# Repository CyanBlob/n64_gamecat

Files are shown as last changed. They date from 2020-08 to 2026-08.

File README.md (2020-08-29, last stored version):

# N64 GameCat

This is a free, open-source implementation of a Nintendo 64 cheating device, akin to the GameShark. It's currently based around the Kendryte K210 SoC (using the Sipeed MAiX BiT breakout), which I chose due to the high number of configurable IO (the N64 cartridge has 50 pins, though many of those aren't necessary for this project). I may eventually add support for ESP32 chips to the GameCat as well.

## Building
This is a PlatformIO project (https://platformio.org/), so building and uploading are relatively straightforward. Simply install PlatformIO (and make sure to add it to your $PATH), and then run `platformio run --target upload --target monitor` with the MAiX BiT plugged in. If it complains about `udev` rules, follow the link it provides.

## Circuits/schematics
I have some test PCBs on order (files are in the `/pcb` directory, made with KiCad EDA). Once I get the design for those finalized it should be as simple as ordering a PCB, soldering the MCU on, and soldering on a cartridge slot
#### Note:
When ordering a cartridge slot, it's important to get one with 2.5mm pin spacing. I've seen several only with 2.54mm spacing, which may not work on this PCB (or with the cartridges in general). I'm using this $2.50 version from AliExpress: https://www.aliexpress.com/item/33002915153.html?spm=a2g0s.9042311.0.0.1ec84c4dN5ezxJ

## FAQ
### Why do this?
I was bored, and that's literally the only reason. If you want to cheat at N64 games, you're likely much better off with an emulator.

### I looked at the PCB. Won't the cartridge end up being parallel with the console if I solder the cartridge slot on it?
Yes.
### Why?
I have no idea what I'm doing.

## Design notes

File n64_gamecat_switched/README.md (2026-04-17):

# N64 Gamecat (Switched)

An RP2350-based interposer that sits between an N64 cartridge and the console,
watches reads on the cart bus, and injects override values for chosen
addresses. Useful for cheats, patching protected boot words, or serving
synthetic data to the console.

This document covers the hardware topology, the N64 cartridge bus protocol as
it appears on the wire, and how the firmware's two PIO state machines plus the
C main loop cooperate to pull it off in real time.

---

## 1. Hardware topology

The board uses a bidirectional bus switch (CBT family) that can electrically
isolate the cartridge from the console's multiplexed address/data bus. The
`CART_EN` GPIO is wired directly to the CBT's active-low `/OE`, so
`CART_EN = 0` closes the switch (cart and console talk directly; the RP2350
just observes) and `CART_EN = 1` opens it (cart is cut off; the RP2350 drives
AD[15:0] for a single /READ pulse).

```
             console edge                              cartridge edge
                  │                                         │
      ALE_L ─────►┼───────────────────────────────────────► │
      ALE_H ─────►┼───────────────────────────────────────► │
      /READ ─────►┼───────────────────────────────────────► │
     /WRITE ─────►┼───────────────────────────────────────► │
                  │                                         │
                  │          ┌───────────────────┐          │
   AD[15:0] ◄════►┼═════════►│  CBT bus switch   │◄════════►│ AD[15:0]
                  │          │   OE = CART_EN    │          │
                  │          └─────────┬─────────┘          │
                  │                    │                    │
                  │            tap to RP2350 GPIO           │
                  │                    │                    │
                  ▼                    ▼                    ▼
            ┌────────────────────────────────────────────────────┐
            │                      RP2350                        │
            │                                                    │
            │   GPIO12..27 ─ AD[0..15]  (bidirectional)          │
            │   GPIO28     ─ ALE_L   (input)                     │
            │   GPIO29     ─ ALE_H   (input)                     │
            │   GPIO30     ─ /READ   (input)                     │
            │   GPIO31     ─ /WRITE  (input)                     │
            │   GPIO10     ─ CART_EN (output, sideset)           │
            │   GPIO11     ─ KILL    (input w/ pull-up)          │
            └────────────────────────────────────────────────────┘
```

Key properties this depends on:

- The CBT switch's propagation delay is single-digit ns, so toggling
  `CART_EN` effectively hands off the bus in one PIO cycle.
- AD pins are driven by the RP2350 *only* while `CART_EN = 0`, so there is no
  window where both sides drive the same net.
- KILL is a dead-man switch: pulling it low makes the firmware stop issuing
  overrides, leaving the cart in permanent pass-through.

---

## 2. The N64 cartridge bus, briefly

The cart bus is a multiplexed 16-bit bus. A single "burst" (one transaction)
looks like:

```
  Address phase                 Data phase (up to 256 words)
  ┌──────────────┐   ┌──┐   ┌──┐   ┌──┐
  │  latch addr  │   │RD│   │RD│   │RD│  ...
  └──────────────┘   └──┘   └──┘   └──┘

                  ▲       ▲       ▲
                  └─ each /READ low pulse delivers one 16-bit halfword.
                     A 32-bit word takes two consecutive /READ pulses.
```

The two ALE signals encode which 16 bits of the 32-bit address are on AD
during the address phase:

| ALE_L | ALE_H | AD[15:0] means |
| :---: | :---: | :--- |
| 1 | 1 | upper half of address (bits 31..16) |
| 1 | 0 | lower half of address (bits 15..0)  |

ALE_L stays high across both sub-phases; only ALE_H toggles within. The wiki
tells us AD is valid on the **falling** edge of each ALE — that's our sampling
rule.

After the address phase, the console issues /READ pulses in sequence. Each
pulse reads one 16-bit halfword from `address + 2*N` where N is the pulse
index within the burst. So an override for the 32-bit word at address A
requires driving AD twice: once on pulse 2*N (upper or lower half, depending
on bit 1 of A) and once on pulse 2*N+1 (the other half).

---

## 3. Firmware architecture at a glance

Three cooperating pieces:

```
  ┌─────────────────────┐     addr      ┌────────────────────┐
  │  n64_capture.pio    │ ─────────────►│  C main loop       │
  │  (watches ALE)      │   RX FIFO     │  (rule engine +    │
  └─────────────────────┘               │   token scheduler) │
                                        └─────────┬──────────┘
                                                  │ tokens
                                                  ▼      TX FIFO
                                        ┌────────────────────────┐
                                        │ n64_respond_tokens.pio │
                                        │ (drives AD + CART_EN)  │
                                        └────────────────────────┘
```

- **Capture SM** watches the ALE pins and pushes a 32-bit address into an
  RX FIFO every time a new burst starts.
- **C main loop** pops the address, looks up which of the next 256 words
  have override rules, and streams `(skip, data)` tokens to the responder.
- **Responder SM** consumes tokens; for each it passes N /READ pulses
  through transparently, then hijacks the next pulse to drive the override
  value on AD with the cartridge electrically disconnected.

The PIO state machines own the nanosecond-level timing; the C loop only
has to keep up at bus-burst granularity.

---

## 4. Capture state machine

### Program (`n64_capture.pio`)

```
wrap_target:
    wait 0 pin 17          ; ALE_H low  (we're between bursts, or in lower phase)
    wait 1 pin 17          ; ALE_H rising: upper-address phase has begun
    wait 0 pin 17          ; ALE_H falling: upper 16 bits of AD are valid
    in   pins, 16          ; ISR[15:0]  = AD[15:0]  (upper half of address)
    wait 0 pin 16          ; ALE_L falling: lower 16 bits of AD are valid
    in   pins, 16          ; ISR[31:16] = prev, ISR[15:0] = AD (lower half)
    push block             ; hand 32-bit address to CPU via RX FIFO
```

`in pins, 16` reads 16 consecutive GPIOs starting at `IN_BASE = AD_BASE`, i.e.
AD[15:0]. With the SM configured for shift-left, two successive `in pins, 16`
instructions leave ISR holding `(upper << 16) | lower` — the full 32-bit
address as the CPU expects it.

### Why these two edges

The wiki tells us AD is valid on the **falling** edge of each ALE, and the
bus timing diagram makes the shape clear:

```
           ┌─────────────────────────────────────────────┐
  ALE_L ───┘                                             └────────
                     ┌─────┐
  ALE_H ─────────────┘     └───────────────────────────────────────
                           ▲                             ▲
                           │                             │
                           A: upper addr valid here      B: lower addr valid here
                              (ALE_H falling)               (ALE_L falling)
```

So within one address burst we need **two** sample moments, and they're on
**different** pins: ALE_H goes high briefly and falls first (point A, upper
half); ALE_L stays high across the whole address phase and falls later
(point B, lower half).

The capture SM therefore waits on both pins, in order:

1. `wait 0 pin 17` / `wait 1 pin 17` — resync by watching ALE_H settle low
   and then rise at burst start. (Using ALE_H for resync is convenient
   because it's the pin that pulses; ALE_L just sits high across the whole
   address phase.)
2. `wait 0 pin 17` — ALE_H's falling edge = point A, upper half captured.
3. `wait 0 pin 16` — ALE_L's falling edge = point B, lower half captured.

Sampling on only one of the two pins would miss half the address — ALE_H
tells us nothing about when the lower half arrives, and ALE_L only gives us
one falling edge per burst.

---

## 5. Responder state machine

### Token format

The C code pushes 32-bit tokens into the responder's TX FIFO. Each token
describes how to handle exactly one /READ pulse:

```
   31                             16 15                             0
  ┌────────────────────────────────┬────────────────────────────────┐
  │          DATA (16 bits)        │          SKIP (16 bits)        │
  └────────────────────────────────┴────────────────────────────────┘

  SKIP = number of /READ pulses to let the real cart answer before we drive
  DATA = the 16-bit value to put on AD during the pulse AFTER those N skips
```

A 32-bit word override is therefore two tokens: one with a skip distance and
the upper-or-lower halfword, followed by one with `skip=0` and the other
halfword (which will land on the immediately-following /READ pulse).

### Program (`n64_respond_tokens.pio`)

```
wrap_target:
    pull block           side 1   ; wait for a token; CART_EN = 1 (cart connected)
    out  x, 16           side 1   ; X = SKIP
    out  y, 16           side 1   ; Y = DATA

    jmp  !x drive_now    side 1   ; SKIP == 0 → drive the very next /READ
    jmp  x-- skip_loop   side 1   ; pre-decrement so body runs exactly SKIP times

skip_loop:                         ; pass SKIP /READ pulses through to the cart
    wait 0 pin 18        side 1
    wait 1 pin 18        side 1
    jmp  x-- skip_loop   side 1

drive_now:
    wait 0 pin 18        side 0   ; /READ falling: cut the cart off the bus
    mov  osr, !null      side 0   ; OSR = 0xFFFFFFFF
    out  pindirs, 16     side 0   ; AD[0..15] → outputs
    mov  osr, y          side 0
    out  pins, 16        side 0   ; drive DATA on AD
    wait 1 pin 18        side 0   ; hold until /READ rises (console latches here)
    mov  osr, null       side 0
    out  pindirs, 16     side 0   ; AD[0..15] → inputs (release bus)
    nop                  side 1   ; reconnect cart and loop back for next token
```

### Flow per token

```
   ┌──────────┐    SKIP=0        ┌──────────┐
   │  wait    │─────────────────►│ drive    │
   │  for     │                  │ this     │
   │  token   │◄─── wrap ────────│ /READ    │
   └────┬─────┘                  └──────────┘
        │ SKIP > 0                    ▲
        ▼                             │
   ┌──────────┐   each /READ          │
   │skip_loop │────(cart answers)────►│
   │          │   X-- until 0         │
   └──────────┘                       │
        └──────── fall through ───────┘
```

### Why `jmp x-- skip_loop` appears twice

`jmp x--` is *post*-decrement: it tests X, takes the branch if X ≠ 0, then
decrements. That means loading X = N and entering a `jmp x-- loop` body runs
the body N+1 times, not N. The first `jmp x-- skip_loop` outside the loop
body is a pre-decrement trick: it always jumps (X ≥ 1 here because we already
handled SKIP = 0 above) and reduces X by 1 on the way in, so the loop body
then executes exactly SKIP times. Small instruction, easy to get wrong — the
initial version of this firmware had an off-by-one here.

### Why 16-bit drive needs `out pindirs`, not `set pindirs`

PIO's `set` instruction writes at most 5 pins at a time. Our AD bus is 16,
so `set pindirs, …` would silently drive only part of the bus and leave the
rest floating. Loading `OSR = 0xFFFFFFFF` and issuing `out pindirs, 16`
instead gives us a proper 16-bit-wide pindir flip, using the OUT pin
configuration set up from C.

---

## 6. The C main loop

Per-burst algorithm:

```
  1. Block until capture FIFO has an address.
  2. Read the 32-bit base address.
  3. Reset the responder SM + clear its FIFO + re-enable it.
     (This aligns the responder's skip-counting with the first /READ
      pulse of the new burst, and drops any leftover tokens.)
  4. If KILL is asserted, skip all scheduling → cart pass-through.
  5. For w in 0..255:
        addr_w = base_word + w*4
        if a rule matches addr_w:
            compute how many halfread pulses since our last token
            push token #1: (skip, first-half-of-word)
            push token #2: (0,    second-half-of-word)
```

The "first half" vs "second half" depends on bit 1 of the base address
(which half of a 32-bit word the console is reading first in this burst).
The scheduler only pushes tokens for *matching* rules, so a burst with no
rule hits produces no tokens and the responder sits at `pull block`
harmlessly — the cart answers every read unchanged.

### Rules

Rules are a small const table compared in `lookup_resp32`:

```c
typedef struct { uint32_t mask, match, resp32; bool enable; } rule_t;

static const rule_t rules[] = {
    { 0xFFFFFFFCu, 0x10000000u, 0x8037FF40u, false },  // first header word
    { 0xFFFF0000u, 0x12000000u, 0xDEADBEEFu, true  },  // 64KB window demo
};
```

A rule matches if `(addr_word & mask) == (match & mask)`. The mask is
compared at 32-bit word granularity, so the scheduler can iterate per-word
and the PIO side doesn't need to know about rules at all.

---

## 7. Timing budget

Numbers below are at the current 300 MHz system clock (1 PIO cycle = 3.3 ns).

| Event | Budget (bus) | Actual (RP2350) | Margin |
| :--- | :--- | :--- | :----- |
| /READ falling → RP2350 drives AD | ~600 ns | ~5 PIO cycles ≈ 17 ns + sync latency | ~35× |
| Address latched → token0 ready in FIFO | ~1 µs (fast bus) | scheduler-bound, single-digit µs worst case | tight-but-fine if word 0 isn't a hit |
| Cart isolate → cart release on bus | — | CBT switch prop ~5 ns | safe |

The PIO side has roughly an order of magnitude of headroom on every
critical edge. The only tight window is the C scheduler's turnaround
between the end of address latching and the first /READ pulse, and only
if word 0 of that burst is a rule hit. If that ever becomes an issue,
options are: precompute per-address token lists, skip the full SM restart
and use a burst-generation counter instead, or hand the scheduler to core
1.

---

## 8. File map

| File | What it is |
| :--- | :--- |
| `n64_capture.pio` | PIO program that latches the 32-bit cart bus address |
| `n64_respond_tokens.pio` | PIO program that skips N reads then drives one override |
| `n64_gamecat_switched.cpp` | Rule table, token scheduler, PIO setup |
| `CMakeLists.txt` | Pico SDK build config (board: solderparty_rp2350_stamp_xl) |

---

## 9. Bring-up checklist

- [ ] Scope ALE_L, ALE_H, /READ with no firmware running — confirm the cart
      bus is behaving as the wiki describes.
- [ ] Flash firmware, set one rule to match some boring cart address, scope
      CART_EN: it should briefly drop once per matching halfread.
- [ ] Add a rule whose first read is visible in-game (e.g. a known texture or
      string) and confirm the override shows up.
- [ ] Pull KILL low and confirm overrides stop immediately.

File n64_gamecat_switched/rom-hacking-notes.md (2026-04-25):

# N64 ROM Hacking Notes

A reference for what we figured out together while bringing up the Gamecat
interceptor. Organized by topic so you can jump in.

---

## 1. Tools

### Emulators (Mac-friendly)

| Tool | Strength | When to use |
| :--- | :--- | :--- |
| **Ares** | Cycle-accurate; built-in memory editor, breakpoints, disassembler, tracer | Default for everything on Mac. Both debugging *and* hardware-accuracy validation. |
| **simple64** | Accuracy, no debugger | Sanity-check that a patched ROM plays correctly. |
| **Project64 + debugger** | Best ROM-hacking UX, but Windows-only | Run via Whisky (Wine wrapper) on Mac if a tutorial demands its specific UI. |
| **Whisky** | Wine wrapper for Mac with Apple Game Porting Toolkit | Lighter than a VM for old Windows tools like PJ64. |
| **UTM / Parallels** | Full Windows VM | Last resort. UTM is free; Parallels is paid but more polished. |

**Rule of thumb:** start with Ares. It does both jobs natively.

### Static analysis

- **Ghidra** — disassembler/decompiler. Use language `MIPS:BE:64:default` (big-endian, 64-bit, original MIPS — *not* MIPS R6).
- **N64 Ghidra Loader** (e.g. `zeroKilo/N64LoaderWV`) — auto-maps ROM segments and the cart header. Versions of the loader must match your Ghidra version exactly. If no prebuilt match exists, install JDK 17+ and `gradle` and build from source: `export GHIDRA_INSTALL_DIR=/Applications/ghidra_X.Y_PUBLIC; gradle`.
- **OoT decomp (`zeldaret/oot`)** — for OoT specifically, this is more powerful than any disassembler. Working C source built byte-identical to the ROM, with full symbol names.

### CLI / scripting

- **`xxd`** — hex dump and pattern search.
- **`mips-linux-gnu-objdump`** — disassembler. For OoT, the bundled binary is at `tools/egcs/macos/objdump`.
- **`strings -tx <file>`** — print all readable ASCII strings with file offset.
- **Python** — for ROM file patching, see snippet in §6.

---

## 2. ROM Identification

The cart header (first 0x40 bytes) tells you everything:

| Offset | Bytes | Meaning |
| :----- | :---- | :--- |
| `0x00` | 4 | Endianness indicator (`80 37 12 40` for canonical `.z64` big-endian) |
| `0x10` | 4 | CRC1 |
| `0x14` | 4 | CRC2 |
| `0x20` | 20 | Internal name (e.g. `"THE LEGEND OF ZELDA "`) |
| `0x3B` | 1 | Media type (`N`=cart, `C`=expandable cart, `D`=64DD) |
| `0x3C` | 2 | Game ID (e.g. `"ZL"` for Zelda) |
| `0x3E` | 1 | **Country code** (`E`=US, `J`=Japan, `P`=PAL, etc.) |
| `0x3F` | 1 | **Version** (`0x00`=v1.0, `0x01`=v1.1, `0x02`=v1.2) |

**Quick identification commands:**
```bash
xxd -s 0x20 -l 20 rom.z64        # internal name
xxd -s 0x3B -l 5 rom.z64          # media + game ID + country + version
xxd -s 0x10 -l 8 rom.z64          # CRC1 + CRC2
md5 rom.z64                        # for hash comparison against known dumps
```

**Endianness gotcha:** OoT and most N64 ROMs come in three formats:
- `.z64` — big-endian, "correct"; first 4 bytes = `80 37 12 40`
- `.v64` — byte-swapped (Doctor V64 backup format)
- `.n64` — word-swapped

Tools like the OoT decomp expect `.z64`. Convert with `tool64`, `n64chksum`, or `ucon64`.

---

## 3. The N64 Cart Bus & Boot Process

### Two distinct security checks

1. **CIC ↔ PIF challenge-response** — hardware-level, between cart's CIC chip and console's PIF. Continuous. Cannot be bypassed from cart-bus side. As long as the inserted cart's CIC works, this is handled.

2. **Bootcode CRC** — software check. The bootcode CRCs the first 1MB of ROM data (`0x10001000` to `0x10101000` on the cart bus, exclusive) and compares to `CRC1`/`CRC2` in the header. This is the one we work around.

### CIC types (relevant for bypass)

| CIC | Examples | Bypass NOP offsets |
| :-- | :--- | :--- |
| 6101 | Star Fox 64 | 0x670, 0x67C |
| 6102/7101 | SM64, Mario Kart 64, most NTSC | 0x66C, 0x678 |
| 6103/7103 | Paper Mario | 0x63C, 0x648 |
| **6105/7105** | **Zelda OoT, Majora's Mask** | **0x77C, 0x788** |
| 6106/7106 | Yoshi's Story, F-Zero X | (not in en64 wiki) |

### CRC bypass

NOP the two `BNE` instructions in the bootcode at the offsets above. Both live in the bootcode region (0x40–0x1000), which is *outside* the CRC window — so NOPing them doesn't itself change the CRC. Once NOP'd, you can patch anywhere in cart ROM.

In the Gamecat firmware, this is `N64_CIC_TYPE` macro. `sim/check_rules.py` validates rules vs the CRC window.

### Compression — the big constraint

OoT (and most N64 games) compress most cart segments with **Yaz0**:
- Cart bus reads = compressed bytes
- Boot stub decompresses into RAM
- Game runs from RAM

**An interceptor sitting on the cart bus cannot meaningfully patch values inside compressed segments** — there's no byte-level mapping between compressed bytes and the decompressed values they produce. Patching one compressed byte corrupts the entire stream from that point.

Find which segments are compressed:
```bash
# In the OoT decomp directory:
awk '/^beginseg/,/^endseg/' spec/spec | \
    awk '/^beginseg/{seg=""; comp="no"} /name/{seg=$2} /compress/{comp="yes"} /^endseg/{print comp, seg}' | \
    sort | uniq
```

For OoT specifically:
- ✓ **Patchable:** `boot`, `dmadata`, `makerom`, all `*_message_data_static` (dialog!), `Audiobank`/`Audioseq`/`Audiotable`, all `vr_*_pal_static` (skybox palettes), map textures
- ✗ **Off-limits:** `code` (game logic, save defaults), all `ovl_*` (actor/scene code), `nintendo_rogo_static`, `title_static`, all `anime_*` (Link's animations), all `vr_*_static` without `_pal` (skybox images)

---

## 4. Finding Patches: Investigation Workflows

### Workflow A — Decomp source grep (best for OoT)

```bash
# Find the C code for the value you want to change
cd oot
grep -rn "healthCapacity\|playerData" src/code/ | head
```

If the value is in `static` data, it'll be in something like `z_sram.c` as an initializer:
```c
static SavePlayerData sNewSavePlayerData = {
    ...
    0x30,    // healthCapacity   <- this is your target
    ...
};
```

### Workflow B — Memory write breakpoint (for runtime values)

In Ares (or PJ64 + debugger):
1. Start the game, get the value to its initial state.
2. In the memory editor, find the RAM address holding the value.
3. Set a memory **write** breakpoint on that address.
4. Trigger the action that changes the value (start a new save, take damage, etc).
5. The debugger pauses at the instruction that wrote it. Note the PC.
6. Convert the PC to a ROM offset (see §5).

### Workflow C — Pattern search

If you know the bytes, search for them directly:
```bash
SIG="dfdfdfdfdfdfdfdf0000003000300030"   # 16+ bytes is usually unique
xxd -p rom.z64 | tr -d '\n' | grep -boE "$SIG" | head
# Result: <hex_offset>:<matched_bytes>
# File offset = hex_offset / 2 (since each byte is 2 hex chars)
```

Useful when you've found bytes via Workflow A but want the offset in a *different* ROM (e.g. building against JP, but patching US).

### Workflow D — Object file inspection

For static C variables that don't appear in the linker map (`static` C symbols often don't):
```bash
# Find which .o file has the data
grep "z_sram" build/ntsc-1.2/oot-ntsc-1.2.map | head
# Note the .data section's RAM address

# Dump the actual bytes
tools/egcs/macos/objdump -s -j .data build/ntsc-1.2/src/code/z_sram.o
# Find your target byte sequence in the output
```

---

## 5. Translating Symbols to ROM Offsets

### From a RAM address to a cart-bus address

Cart ROM is mirrored at `0x10000000` on the N64 bus. To convert:

```
cart_bus_addr = 0x10000000 + (file_offset_in_rom)
```

To get the ROM file offset of a RAM address:
1. Find the **segment** containing that RAM address (look in `oot-ntsc-X.X.map` or `dmadata`).
2. Each segment's RAM-to-ROM mapping is in the map under `LOAD` lines or in the `dmadata` table.
3. `rom_offset = segment_rom_start + (ram_addr - segment_ram_start)`

### From a `static` C variable to its ROM offset

`static` symbols are usually stripped from ELF symbol tables. Workflow:
1. Find the object file's `.data` section RAM address from the map (`grep "<file>.o" *.map`).
2. Dump the section: `objdump -s -j .data <file>.o`.
3. Find your bytes by inspection. The byte position within `.data` is your offset within the section.
4. RAM addr = section RAM base + position.
5. Convert to cart-bus address as above.

### Quickest method: skip the math, pattern-match

Once you have the bytes from `objdump`, just `grep` for them in the actual ROM file. The match offset (divided by 2 for `xxd -p` output) is your ROM file offset. This works even when the source decomp targets a different ROM version than you have, because data structs are usually region-independent.

---

## 6. ROM Patching Mechanics

### Apply patches to a ROM file (for emulator testing)

```python
# tools/patch_rom.py
import shutil, struct, sys

src, dst = sys.argv[1], sys.argv[2]
shutil.copy(src, dst)

# (cart_bus_addr, 32-bit value)  — addr must be word-aligned
patches = [
    (0x10ABC123 & ~0x3, 0x00000140),
]

with open(dst, "r+b") as f:
    for cart_addr, value in patches:
        rom_offset = cart_addr - 0x10000000
        f.seek(rom_offset)
        f.write(struct.pack(">I", value))   # big-endian (Z64)
```

Run: `python3 tools/patch_rom.py orig.z64 patched.z64`. Load `patched.z64` in Ares to verify before flashing your interceptor.

### Convert to a Gamecat interceptor rule

```c
{ 0xFFFFFFFCu, <cart_bus_addr & ~0x3>, <new_32bit_value>, true },
```

Word-aligned (mask `~0x3`). Always read the original 32-bit word at the aligned address first, so you know which 16-bit half to modify and which to preserve:

```bash
xxd -s <aligned_offset> -l 4 rom.z64
```

---

## 7. MIPS Reading Tips

### Common N64 conventions

- Big-endian. Always.
- 32-bit MIPS code mostly, with occasional 64-bit (`ld`, `sd`, `daddiu`) — that's why Ghidra needs the 64-bit language variant.
- IDO-compiled (SGI's compiler), not GCC. Expect odd patterns: heavy delay-slot use, weird register allocation, `lui`/`addiu` pair construction for full 32-bit immediates.

### Distinguishing data values from stack offsets

When searching disassembly for "0x30" (or any small constant), most hits will be **stack manipulations**, not values:

```mips
addiu sp, sp, -0x30           ; allocating 48 bytes of stack
addiu sp, sp,  0x30           ; deallocating it
sw  $reg, Stack[0x30](sp)     ; spilling to stack offset 0x30
lw  $reg, Stack[0x30](sp)     ; reloading
sw  $reg, 0x30(t3)            ; writing to *struct offset* 0x30
```

The actual value-loading patterns:
```mips
li   $t0, 0x30                ; load immediate (a real value!)
addiu $t0, $zero, 0x30        ; same thing (li expands to this)
ori  $t0, $t0, 0x30           ; sometimes used for low halves of larger values
```

Filter out stack noise to find the real constants.

### MIPS NOP

`0x00000000` is the canonical NOP (`sll $zero, $zero, 0`). Useful for patching out a branch you want to neutralize.

### Patching a load-immediate

If `addiu $t0, $zero, 0x0030` encodes as `0x24080030`, change the immediate:
- `addiu $t0, $zero, 0x0140` = `0x24080140`

Lower 16 bits of the instruction = the immediate.

---

## 8. Game Genie vs GameShark — the Conceptual Divide

### Game Genie (NES, SNES, Genesis)

Sat between cart and console. Watched the address bus. On each ROM read at a programmed address, substituted a different data value.

**Codes encode:** address + value + (optional) compare. Substitution cipher of letters to nibbles, then shuffled into fields.

**Your interceptor is electrically a Game Genie.** For platforms with existing Game Genie code libraries, you can decode codes directly into your `rules[]` table. **N64 never had a Game Genie**, so no preexisting library exists.

### GameShark (PS1, GBA, N64, etc.)

Plugged between cart and console, but works completely differently:
- Has its own onboard ROM with its own bootcode.
- Hijacks the boot vector — runs *its* code first.
- Installs an NMI handler that fires periodically.
- On each NMI, walks the user's enabled cheat list and writes new values into RAM.

**GameShark patches RAM, not ROM.** Your interceptor cannot directly use N64 GameShark codes because RAM doesn't go through the cart bus.

**N64 GameShark code formats:**
```
80XXXXXX 00YY   write byte 0xYY to RAM 0x8000_XXXX (every frame)
81XXXXXX YYYY   write halfword 0xYYYY to RAM 0x8000_XXXX (every frame, aligned)
D0XXXXXX 00YY   conditional: execute next code only if RAM[0x8000_XXXX] == 0xYY
F0XXXXXX 00YY   write once at startup
```

A GS code can be a *hint* to your ROM hacking — it tells you what address holds a value. Then use Workflow B/C from §4 to find the *instruction* that writes to that address, and patch the instruction in ROM.

---

## 9. Common Pitfalls

| Pitfall | Why | Fix |
| :--- | :-- | :-- |
| ROM CRC mismatch with decomp | You have the wrong region/version (e.g. US ROM but built `ntsc-1.2` which is JP) | Match `baseroms/<name>/` to your country code byte |
| `make setup` fails on Mac with `lld` errors | macOS lld doesn't support Mach-O | Patch `tools/fado/Makefile` to skip lld on Darwin |
| Asset extraction fails with type-union error | Python 3.9 doesn't support `str \| tuple` syntax | `brew install python@3.12`, recreate `.venv` |
| ROM build fails with "ld: unknown options: -T" | Passed `LD=ld` poisons the MIPS cross-link too | Patch the host-tool Makefile instead; don't pass `LD=ld` to the ROM build |
| `static` symbols don't appear in linker map | IDO strips static C symbols | Use `objdump -t <file>.o` and look at the `.data` section bytes directly |
| Pattern not found in compressed ROM | The data is in a Yaz0 segment | See §3 (compression). Targets in compressed segments need a flashcart, not the interceptor |
| Search for `0x30` returns hundreds of hits | Most are stack offsets, not values | See §7; filter `addiu sp` and `sw/lw ... Stack[...]` |
| Ghidra disassembly has gaps / "invalid instruction" | Picked 32-bit MIPS variant | Switch to `MIPS:BE:64:default` |

---

## 10. OoT-Specific Knowledge

### Versions

- `ntsc-1.0/1.1/1.2` in the decomp = **Japanese** NTSC (despite the name)
- `pal-1.0/1.1` = European PAL
- `gc-*` = GameCube ports (multiple variants including Master Quest debug)
- `ique-cn` = Chinese iQue version
- US N64 versions (NTSC US 1.0/1.1/1.2) often **not directly supported** by older decomp commits — translate by pattern-matching from JP versions

### Save data layout (`SavePlayerData` struct, from z_sram.c)

In `sNewSavePlayerData` (the new-game template):
- offset 0x00: `newf[6]` — magic bytes for valid save (all zero in template)
- offset 0x06: `deaths` (s16)
- offset 0x08: `playerName[8]` — eight `FILENAME_SPACE` bytes (`0xDF`)
- offset 0x10: `n64ddFlag` (s16)
- offset 0x12: `healthCapacity` (s16) — **0x30 in template (3 hearts)**
- offset 0x14: `defense` (s16)
- offset 0x16: `magicLevel` (s8)
- offset 0x17: `magic` (s8)
- ... etc

`health` (current) is **not** in the static template — it's set at runtime to equal `healthCapacity`. So patching only `healthCapacity` is enough.

`MAGIC_NORMAL_METER` = 0x30 (just to confuse pattern matching).

The second `0xE0` healthCapacity in the source is for `sDebugSavePlayerData` (14-heart debug save).

### CIC

OoT NTSC and PAL use CIC **6105** / **7105** (Zelda type). Set `N64_CIC_TYPE=6105` in firmware for either US or JP NTSC.

### Strategic notes

- `code` is compressed → **save data, hearts, items, anything in game logic is unreachable to a cart-bus interceptor**.
- `nes_message_data_static` (English dialog) is **uncompressed** → text changes work great with the interceptor.
- For "max starting hearts on a real cart": modify `z_sram.c` line 104, `make`, flash to an EverDrive. The interceptor is the wrong tool for this specific job.

---

## 11. The OoT Decomp Build (macOS)

### One-time setup

```bash
brew install python@3.12 gradle openjdk@21    # pip is not enough; need Python 3.10+

cd oot
rm -rf .venv
python3.12 -m venv .venv
```

Patch `tools/fado/Makefile` around line 27:

```make
ifneq ($(LLD),0)
  LDFLAGS   += -fuse-ld=lld
else ifneq ($(shell uname -s),Darwin)
ifneq ($(LD),ld)
  LDFLAGS   += -fuse-ld=lld
endif
endif
```

Also patch `tools/Makefile` around line 27 with the same `Darwin` check.

### Build

```bash
make setup VERSION=ntsc-1.2 LLD=0
make VERSION=ntsc-1.2 LLD=0
```

Output: `build/ntsc-1.2/oot-ntsc-1.2.elf` and `oot-ntsc-1.2.z64`, plus `oot-ntsc-1.2.map` (the symbol map).

---

## 12. Quick Command Reference

### Identify a ROM
```bash
xxd -s 0x20 -l 20 rom.z64                          # internal name
xxd -s 0x3B -l 5 rom.z64                            # game ID + country + version
md5 rom.z64
```

### Find a byte signature in a ROM
```bash
SIG="dfdfdfdfdfdfdfdf0000003000300030"
xxd -p rom.z64 | tr -d '\n' | grep -boE "$SIG"
# Convert hex offset to file offset: divide by 2
```

### Inspect a 4-byte word at a specific offset
```bash
xxd -s 0xABCDEF -l 4 rom.z64
```

### Dump a function's disassembly
```bash
mips-linux-gnu-objdump -d -j .text --disassemble=Sram_InitNewSave build/.../code.elf
```

### Dump a section's raw bytes
```bash
mips-linux-gnu-objdump -s -j .data build/.../z_sram.o
```

### List all sections of a binary
```bash
mips-linux-gnu-objdump -h build/.../oot.elf
```

### Find a symbol's address
```bash
mips-linux-gnu-nm -n build/.../oot.elf | grep Sram_InitNewSave
# Or in the map:
grep "Sram_InitNewSave" build/.../oot-ntsc-1.2.map
```

### Find readable strings in a ROM
```bash
strings -tx rom.z64 | grep -i "danger\|hello"        # offsets in hex
```

### Verify the Gamecat interceptor's rules
```bash
python3 sim/check_rules.py n64_gamecat_switched.cpp --cic 6105
```

### Run the Gamecat simulator
```bash
python3 sim/simulator.py
gtkwave sim/gamecat.vcd
```

---

## 13. The Big Picture for Your Interceptor

After all this work, here's where the Gamecat interceptor genuinely shines on N64:

✓ **Boot-time tricks** — PI bus speed override, CIC bypass NOPs, region/header changes
✓ **Patches in uncompressed segments** — text/dialog (`nes_message_data_static`), audio (`Audiobank`), skybox palettes (`vr_*_pal_static`), map textures
✓ **Things only a cart-bus device can do** — intercept the very first reads, run before the boot ROM has set up anything

✗ **Won't work for:** anything in compressed segments — game logic, save defaults, item data, actor code, compressed assets

For game-logic patches on a real cart, a flashcart with a modified ROM build is the right tool. The interceptor is a Game Genie for an era where Game Genies became mostly impractical due to ROM compression — but it still has its niche, and it's a niche no other consumer device occupies.

---

## 14. Resources

- **en64 wiki** — N64 hardware/cart docs: https://en64.shoutwiki.com/wiki/ROM
- **OoT decomp** — https://github.com/zeldaret/oot
- **Ares** — https://ares-emu.net
- **Ghidra** — https://ghidra-sre.org
- **N64 Ghidra Loader** — https://github.com/zeroKilo/N64LoaderWV (search GitHub for newer/better forks)
- **Whisky** (Wine for Mac) — `brew install --cask whisky`
- **Pico SDK docs** — https://datasheets.raspberrypi.com/pico/raspberry-pi-pico-c-sdk.pdf

---

*Compiled from a long evening's investigation. Future-you: hi, you're welcome.*

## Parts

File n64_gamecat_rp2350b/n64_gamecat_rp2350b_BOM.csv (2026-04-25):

Id | Designator | Footprint | Quantity | Designation | Supplier and ref
1 | A1 | RaspberryPi_Pico_Common_Unspecified | 1 | RaspberryPi_Pico
2 | C1 | C_0805_2012Metric | 1 | 10uF
3 | C2, C3, C4, C5 | C_0402_1005Metric | 4 | 100nF
4 | D1 | LED_0402_1005Metric | 1 | LED
5 | J4 | PinHeader_1x02_P2.54mm_Vertical | 1 | Conn_01x02_Pin
6 | R1, R2, R3, R4 | R_0402_1005Metric | 4 | 10K
7 | R5 | R_0402_1005Metric | 1 | 1K
8 | SW1 | PinSocket_1x03_P2.54mm_Vertical | 1 | SW_SPDT
9 | U1 | N64_cartridge_connecter_2.5mm | 1 | ~
10 | U2 | N64_cartridge_pins_2.5mm | 1 | ~
11 | U3, U4 | DW20 | 2 | SN74CBTLV3245ADW

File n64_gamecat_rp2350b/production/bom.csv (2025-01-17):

Designator | Footprint | Quantity | Value | LCSC Part #
J1, J2 | PinHeader_1x03_P2.54mm_Vertical | 2 | Conn_01x03_Pin
J3 | PinSocket_1x05_P2.54mm_Vertical | 1 | Conn_01x05
U2 | N64_cartridge_connecter_2.5mm | 1 | ~
U3 | N64_cartridge_pins_2.5mm | 1 | ~
U4 | RP2xxx_Stamp_XL_THT | 1 | RP235x-B

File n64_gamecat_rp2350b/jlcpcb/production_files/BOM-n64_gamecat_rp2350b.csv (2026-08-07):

Comment | Designator | Footprint | LCSC | Quantity
100nF | C2,C3,C4,C5 | C_0402_1005Metric | C1525 | 4
10K | R1,R2,R3,R4 | R_0402_1005Metric | C25744 | 4
10uF | C1 | C_0805_2012Metric | C15850 | 1
1K | R5 | R_0402_1005Metric | C11702 | 1
Conn_01x02_Pin | J4 | PinHeader_1x02_P2.54mm_Vertical | C32713268 | 1
LED | D1 | LED_0402_1005Metric | C71911 | 1
RaspberryPi_Pico | A1 | RaspberryPi_Pico_Common_Unspecified | C41407547 | 1
SN74CB3Q3245PWR | U5,U6 | PW20 | C470961 | 2
~ | U1 | N64_cartridge_connecter_2.5mm |  | 1
~ | U2 | N64_cartridge_pins_2.5mm |  | 1

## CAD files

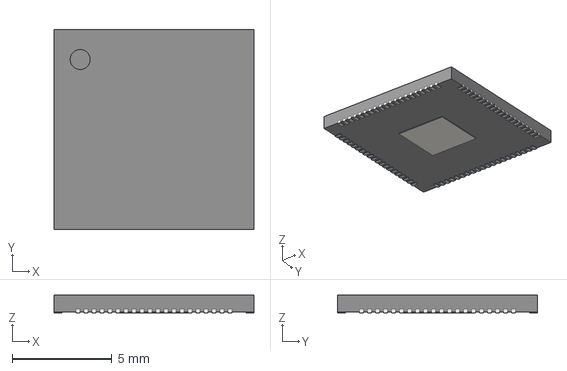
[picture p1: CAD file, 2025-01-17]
RP2350_KiCad-main/RP2350B-QFN80.step
10.0 x 10.0 x 0.9 mm

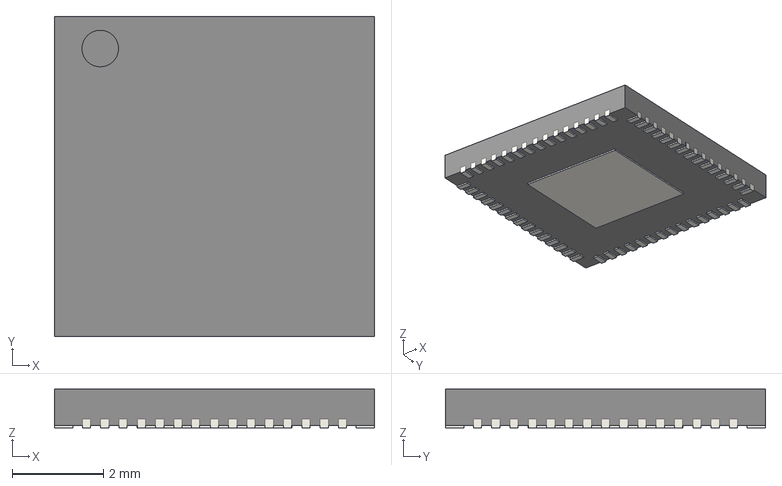
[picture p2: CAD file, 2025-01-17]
RP2350_KiCad-main/RP2350A-QFN60.step
7.00 x 7.00 x 0.85 mm

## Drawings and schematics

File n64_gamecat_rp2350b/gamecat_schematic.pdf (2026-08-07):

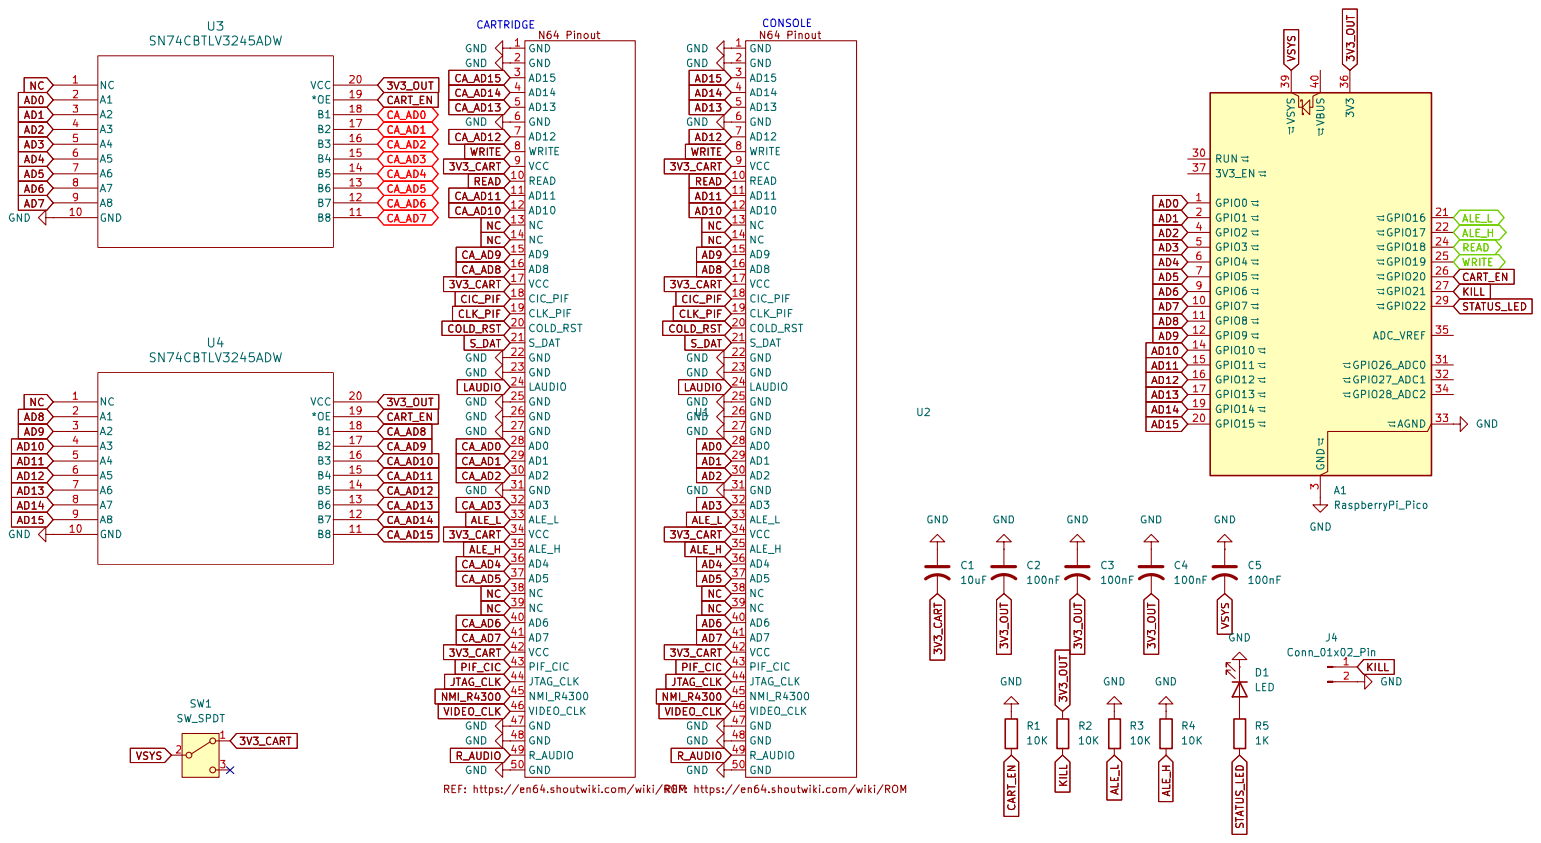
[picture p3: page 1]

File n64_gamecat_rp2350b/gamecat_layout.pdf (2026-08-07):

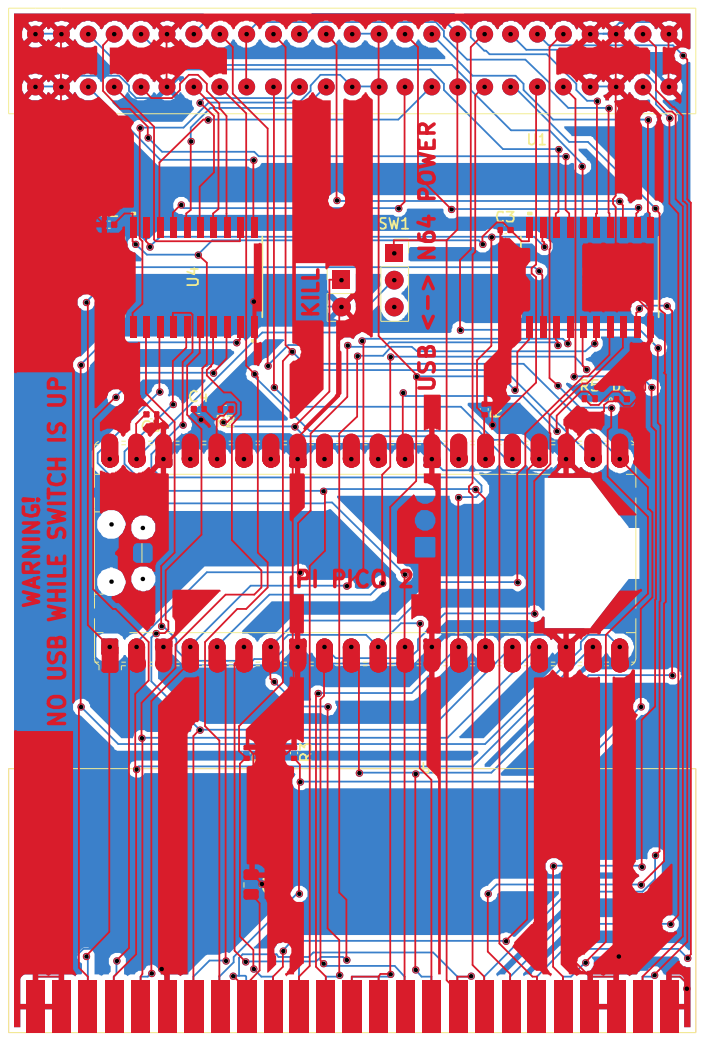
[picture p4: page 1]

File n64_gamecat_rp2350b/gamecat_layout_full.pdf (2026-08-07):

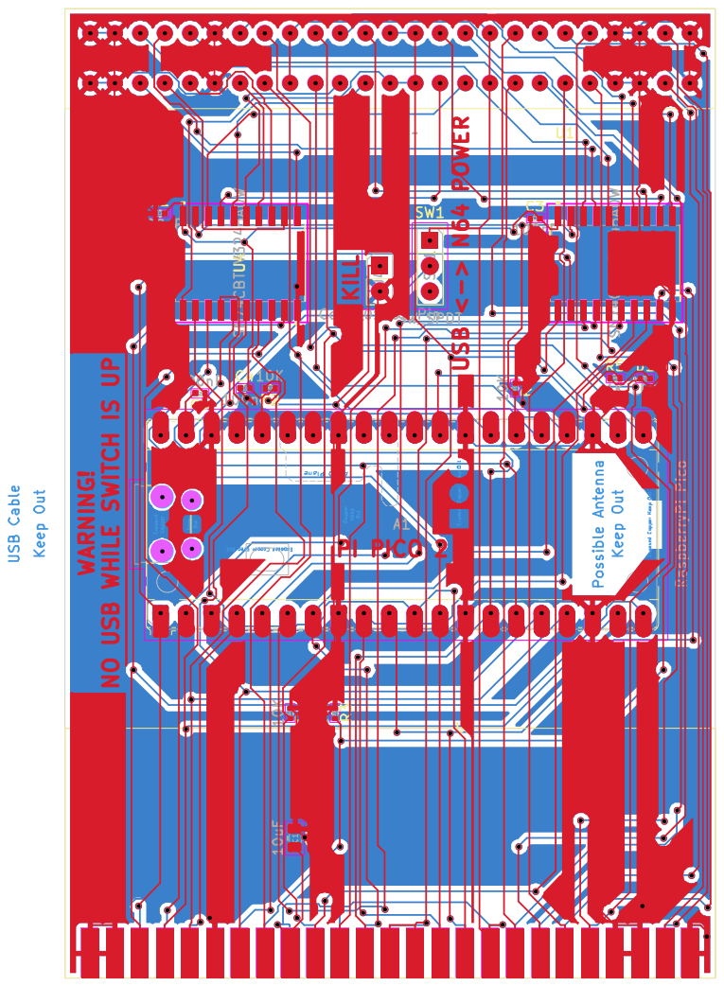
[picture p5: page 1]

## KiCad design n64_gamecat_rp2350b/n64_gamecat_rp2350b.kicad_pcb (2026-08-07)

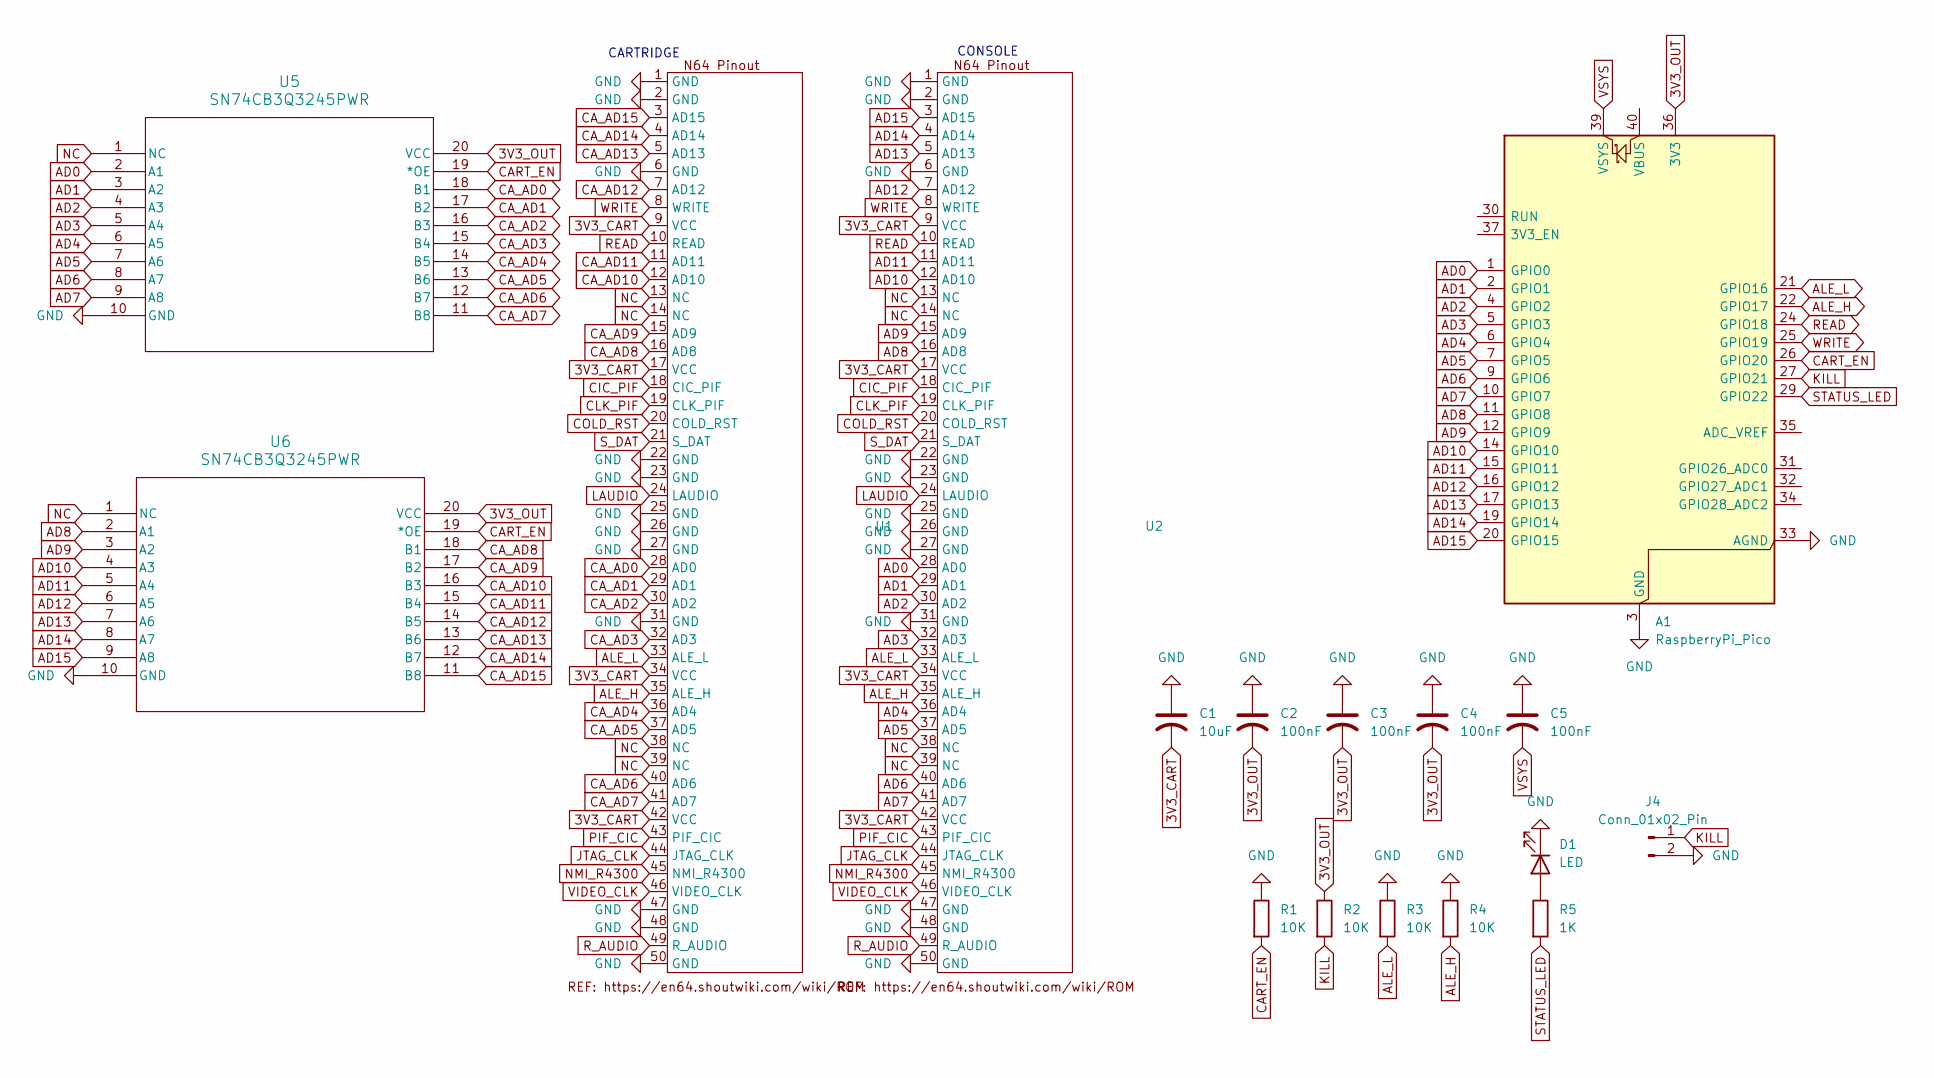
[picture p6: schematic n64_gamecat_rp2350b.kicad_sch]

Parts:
A1: RaspberryPi_Pico; RaspberryPi_Pico_Common_Unspecified
C1: 10uF; C_0805_2012Metric
C2, C3, C4, C5: 100nF; C_0402_1005Metric
D1: LED; LED_0402_1005Metric
J4: Conn_01x02_Pin; PinHeader_1x02_P2.54mm_Vertical
R1, R2, R3, R4: 10K; R_0402_1005Metric
R5: 1K; R_0402_1005Metric
U1: N64_cartridge_connecter_2.5mm
U2: N64_cartridge_pins_2.5mm
U5, U6: SN74CB3Q3245PWR; PW20

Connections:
3V3_CART: C1.2, U1.9 (VCC), U1.17 (VCC), U1.34 (VCC), U1.42 (VCC), U2.9 (VCC), U2.17 (VCC), U2.34 (VCC), U2.42 (VCC)
3V3_OUT: A1.36 (3V3), C2.2, C3.2, C4.2, R2.1, U5.20 (VCC), U6.20 (VCC)
AD0: A1.1 (GPIO0), U2.28 (AD0), U5.2 (A1)
AD1: A1.2 (GPIO1), U2.29 (AD1), U5.3 (A2)
AD2: A1.4 (GPIO2), U2.30 (AD2), U5.4 (A3)
AD3: A1.5 (GPIO3), U2.32 (AD3), U5.5 (A4)
AD4: A1.6 (GPIO4), U2.36 (AD4), U5.6 (A5)
AD5: A1.7 (GPIO5), U2.37 (AD5), U5.7 (A6)
AD6: A1.9 (GPIO6), U2.40 (AD6), U5.8 (A7)
AD7: A1.10 (GPIO7), U2.41 (AD7), U5.9 (A8)
AD8: A1.11 (GPIO8), U2.16 (AD8), U6.2 (A1)
AD9: A1.12 (GPIO9), U2.15 (AD9), U6.3 (A2)
AD10: A1.14 (GPIO10), U2.12 (AD10), U6.4 (A3)
AD11: A1.15 (GPIO11), U2.11 (AD11), U6.5 (A4)
AD12: A1.16 (GPIO12), U2.7 (AD12), U6.6 (A5)
AD13: A1.17 (GPIO13), U2.5 (AD13), U6.7 (A6)
AD14: A1.19 (GPIO14), U2.4 (AD14), U6.8 (A7)
AD15: A1.20 (GPIO15), U2.3 (AD15), U6.9 (A8)
ALE_H: A1.22 (GPIO17), R4.2, U1.35 (ALE_H), U2.35 (ALE_H)
ALE_L: A1.21 (GPIO16), R3.2, U1.33 (ALE_L), U2.33 (ALE_L)
CART_EN: A1.26 (GPIO20), R1.2, U5.19 (*OE), U6.19 (*OE)
CA_AD0: U1.28 (AD0), U5.18 (B1)
CA_AD1: U1.29 (AD1), U5.17 (B2)
CA_AD2: U1.30 (AD2), U5.16 (B3)
CA_AD3: U1.32 (AD3), U5.15 (B4)
CA_AD4: U1.36 (AD4), U5.14 (B5)
CA_AD5: U1.37 (AD5), U5.13 (B6)
CA_AD6: U1.40 (AD6), U5.12 (B7)
CA_AD7: U1.41 (AD7), U5.11 (B8)
CA_AD8: U1.16 (AD8), U6.18 (B1)
CA_AD9: U1.15 (AD9), U6.17 (B2)
CA_AD10: U1.12 (AD10), U6.16 (B3)
CA_AD11: U1.11 (AD11), U6.15 (B4)
CA_AD12: U1.7 (AD12), U6.14 (B5)
CA_AD13: U1.5 (AD13), U6.13 (B6)
CA_AD14: U1.4 (AD14), U6.12 (B7)
CA_AD15: U1.3 (AD15), U6.11 (B8)
CIC_PIF: U1.18 (CIC_PIF), U2.18 (CIC_PIF)
CLK_PIF: U1.19 (CLK_PIF), U2.19 (CLK_PIF)
COLD_RST: U1.20 (COLD_RST), U2.20 (COLD_RST)
GND: A1.3 (GND), A1.8 (GND), A1.13 (GND), A1.18 (GND), A1.23 (GND), A1.28 (GND), A1.33 (AGND), A1.38 (GND), C1.1, C2.1, C3.1, C4.1, C5.1, D1.1 (K), J4.2, R1.1, R3.1, R4.1, U1.1 (GND), U1.2 (GND), U1.6 (GND), U1.22 (GND), U1.23 (GND), U1.25 (GND), U1.26 (GND), U1.27 (GND), U1.31 (GND), U1.47 (GND), U1.48 (GND), U1.50 (GND), U2.1 (GND), U2.2 (GND), U2.6 (GND), U2.22 (GND), U2.23 (GND), U2.25 (GND), U2.26 (GND), U2.27 (GND), U2.31 (GND), U2.47 (GND), U2.48 (GND), U2.50 (GND), U5.10 (GND), U6.10 (GND)
JTAG_CLK: U1.44 (JTAG_CLK), U2.44 (JTAG_CLK)
KILL: A1.27 (GPIO21), J4.1, R2.2
LAUDIO: U1.24 (LAUDIO), U2.24 (LAUDIO)
NC: U1.13 (NC), U1.14 (NC), U1.38 (NC), U1.39 (NC), U2.13 (NC), U2.14 (NC), U2.38 (NC), U2.39 (NC), U5.1 (NC), U6.1 (NC)
NMI_R4300: U1.45 (NMI_R4300), U2.45 (NMI_R4300)
unnamed: D1.2 (A), R5.1
PIF_CIC: U1.43 (PIF_CIC), U2.43 (PIF_CIC)
READ: A1.24 (GPIO18), U1.10 (READ), U2.10 (READ)
R_AUDIO: U1.49 (R_AUDIO), U2.49 (R_AUDIO)
STATUS_LED: A1.29 (GPIO22), R5.2
S_DAT: U1.21 (S_DAT), U2.21 (S_DAT)
VIDEO_CLK: U1.46 (VIDEO_CLK), U2.46 (VIDEO_CLK)
VSYS: A1.39 (VSYS), C5.2
WRITE: A1.25 (GPIO19), U1.8 (WRITE), U2.8 (WRITE)

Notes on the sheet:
CONSOLE
CARTRIDGE

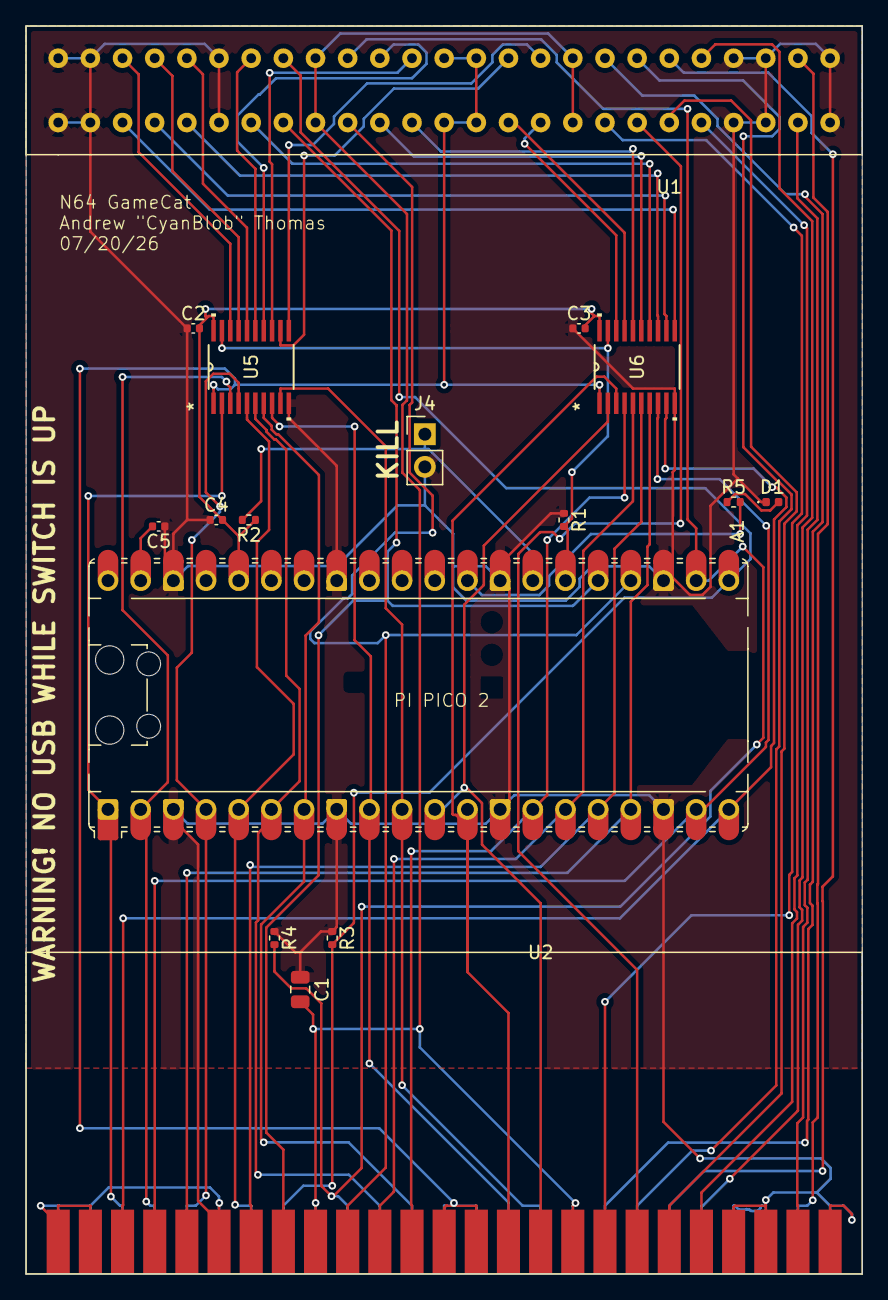
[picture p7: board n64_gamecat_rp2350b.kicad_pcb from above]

Board: 2 copper layers, 65.0 x 97.0 mm, 17 parts (0 on the bottom side), 55 nets.

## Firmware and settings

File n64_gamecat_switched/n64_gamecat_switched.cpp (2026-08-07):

#include <stdio.h>
#include <string.h>
#include "pico/stdlib.h"
#include "hardware/pio.h"
#include "hardware/clocks.h"
#include "hardware/timer.h"
#include "hardware/vreg.h"
#include "n64_capture.pio.h"
#include "n64_respond_tokens.pio.h"
#include "n64_snoop.pio.h"

// RP2350 SDK default is 150 MHz, but the PIO programs and README timing
// budget assume 300 MHz (1 PIO cycle = 3.3ns). Running at the SDK default
// halves the C scheduler's real-world throughput against the token-
// scheduling turnaround the README already flags as the one tight margin
// in the design — likely a contributor to observed override/skip-count
// desync. Bump the core voltage before raising clk_sys, standard practice
// for RP2350 above stock speed.
#define SYSTEM_CLOCK_KHZ 300000

#define DEBUG_PRINT 0
// Snoop-based debug capture (header dump, msgwatch live-stream). Even with
// token scheduling moved ahead of it, per-burst capture overhead in the hot
// loop can still delay servicing of the *next* burst during rapid-fire
// gameplay reads, which is enough to desync override timing. Disable while
// verifying overrides actually work; re-enable only for offline text-hunting
// sessions where correctness of overrides isn't being tested simultaneously.
#define DEBUG_SNOOP 1

/* ========= Pin mapping ========= */
#define AD_BASE         0   // GPIO N..N+15 -> AD[0..15]
#define CART_EN_PIN     20   // sideset to CBT OE/EN (1=connected, 0=isolated)
#define KILL_PIN        21   // pull low to force pass-through
#define STATUS_LED_PIN  22   // D1 on the schematic (heartbeat)

#define ALE_L_PIN_REL   16
#define ALE_H_PIN_REL   17
#define READ_N_PIN_REL  18
#define WRITE_N_PIN_REL 19
#define ALE_L_GPIO      (AD_BASE + ALE_L_PIN_REL)
#define ALE_H_GPIO      (AD_BASE + ALE_H_PIN_REL)
#define READ_N_GPIO     (AD_BASE + READ_N_PIN_REL)
#define WRITE_N_GPIO    (AD_BASE + WRITE_N_PIN_REL)

/* ========= Heartbeat LED =========
 * Driven by a hardware-timer IRQ that fires twice per second.
 * Each callback is ~100 ns of CPU work, only when the IRQ fires —
 * average overhead is ~200 ns / second = 0.00004% of the CPU. The
 * worst-case latency it can add to the burst-scheduling hot path is
 * ~100 ns once per ~500 ms (only when the IRQ happens to overlap a
 * burst), which is well below the C scheduler's existing ~1 µs budget.
 *
 * The PIO state machines are entirely unaffected — they have their
 * own pipelines and run independently of CPU IRQs.
 */
#define HEARTBEAT_PERIOD_MS 500

static bool led_heartbeat_cb(repeating_timer_t* rt) {
    static bool state = false;
    state = !state;

    #if DEBUG_PRINT
    printf("heartbeat: %d\n", state);
    #endif
    gpio_put(STATUS_LED_PIN, state);
    return true; // keep firing
}

/* ========= Bootcode CRC bypass =========
 *
 * The N64 bootcode (running from cart ROM after CIC validation) computes a
 * CRC over ROM offsets 0x1000..0x101000 (cart-bus 0x10001000..0x10101000)
 * and checks it against CRC1/CRC2 in the header. Any patch we make inside
 * that window changes the computed CRC, and the console refuses to start.
 *
 * Per the en64 wiki ("Bypassing bad checksum"), NOPing two specific BNE
 * instructions in the bootcode makes the CRC mismatch branch a no-op, so
 * any subsequent patch — anywhere in ROM — is fine. The two ROM offsets
 * depend on the CIC chip; the bootcode itself lives at 0x40..0x1000 which
 * is *outside* the CRC window, so NOPing those two words doesn't itself
 * change the CRC.
 *
 * To enable, set N64_CIC_TYPE to your cart's CIC family below (or via a
 * -DN64_CIC_TYPE=NNNN compile flag in CMakeLists.txt). Setting it wrong
 * for the inserted cart will NOP unrelated bootcode instructions and the
 * game won't boot — match this to the actual cart. Common pairings:
 *
 *   N64_CIC_TYPE=0      No bypass (use if all patches are outside CRC window)
 *   N64_CIC_TYPE=6101   Star Fox 64 only
 *   N64_CIC_TYPE=6102   "Standard" NTSC: SM64, Mario Kart 64, Banjo-Kazooie,
 *                       most NTSC games        (PAL equivalent: 7101)
 *   N64_CIC_TYPE=6103   Paper Mario, etc.       (PAL equivalent: 7103)
 *   N64_CIC_TYPE=6105   Zelda OoT, Majora's Mask (PAL equivalent: 7105)
 *   N64_CIC_TYPE=6106   Yoshi's Story, F-Zero X — bypass offsets not yet
 *                       documented in the en64 wiki; leave at 0 and patch
 *                       outside the CRC window for these games.
 */
#ifndef N64_CIC_TYPE
#define N64_CIC_TYPE 6105
#endif

#if N64_CIC_TYPE == 0
    #define CIC_BYPASS_RULES /* none */
#elif N64_CIC_TYPE == 6101
    #define CIC_BYPASS_RULES \
        { 0xFFFFFFFCu, 0x10000670u, 0x00000000u, true }, \
        { 0xFFFFFFFCu, 0x1000067Cu, 0x00000000u, true },
#elif N64_CIC_TYPE == 6102 || N64_CIC_TYPE == 7101
    #define CIC_BYPASS_RULES \
        { 0xFFFFFFFCu, 0x1000066Cu, 0x00000000u, true }, \
        { 0xFFFFFFFCu, 0x10000678u, 0x00000000u, true },
#elif N64_CIC_TYPE == 6103 || N64_CIC_TYPE == 7103
    #define CIC_BYPASS_RULES \
        { 0xFFFFFFFCu, 0x1000063Cu, 0x00000000u, true }, \
        { 0xFFFFFFFCu, 0x10000648u, 0x00000000u, true },
#elif N64_CIC_TYPE == 6105 || N64_CIC_TYPE == 7105
    #define CIC_BYPASS_RULES \
        { 0xFFFFFFFCu, 0x1000077Cu, 0x00000000u, true }, \
        { 0xFFFFFFFCu, 0x10000788u, 0x00000000u, true },
#else
    #error "Unsupported N64_CIC_TYPE: must be 0, 6101, 6102/7101, 6103/7103, or 6105/7105"
#endif

/* ========= Cheats =========
 * mask / match compare at 32-bit word granularity.
 * resp32 is the value served for matched words.
 */
typedef struct { uint32_t mask, match, resp32; bool enable; } rule_t;


// NOTE: 0x10001000–0x10101000 (first 1MB of cart address space) is CRCed
// sim/check_rules.py checks this
static const rule_t rules[] = {
    // Bootcode CRC bypass (gated by N64_CIC_TYPE above; expands to nothing
    // when N64_CIC_TYPE == 0).
    //CIC_BYPASS_RULES

    // Inject PI bus-timing override 0x8037FF40 as the first header word.
    // (Wiki: setting this value slows all bus activity — useful for debugging.)
    //{ 0xFFFFFFFCu, 0x10000000u, 0x8037FF40u, false },

    // Demo: override a 64KB window with a recognisable value.
    //{ 0xFFFF0000u, 0x12000000u, 0xDEADBEEFu, true },

    // "fairy"->"butt " in the Deku Tree's Kokiri-forest speech, V1.1 (this
    // cart, confirmed via live CRC2 = 0x021E1E19). Addresses/values computed
    // directly from real bytes snooped live off the cart bus — not from a
    // baserom file, since no genuine V1.1 dump was available.
    //
    // The first attempt at these (now corrected) was wrong: the snoop
    // capture occasionally includes a spurious leading 0x0000 halfword
    // before the real burst data (a reset-timing race, not real ROM
    // content) — comparing two captures of the same address caught it, one
    // had it and one didn't. Values below are from the artifact-free
    // capture; cross-check any newly-added address the same way before
    // trusting it.
    { 0xFFFFFFFCu, 0x1091F338u, 0x62757474u, true },
    { 0xFFFFFFFCu, 0x1091F33Cu, 0x202E0E3Cu, true },
    { 0xFFFFFFFCu, 0x1091F378u, 0x61206275u, true },
    { 0xFFFFFFFCu, 0x1091F37Cu, 0x7474202Eu, true },

    // Below: the original 100 rules generated against the WRONG revision
    // (V1.2 baserom) — this cart is V1.1. Left disabled/for reference; do not
    // enable without regenerating against real V1.1 bytes first.
#if 0
    { 0xFFFFFFFCu, 0x1090D094u, 0x42757474u, true },
    { 0xFFFFFFFCu, 0x1090D098u, 0x2020536Cu, true },
    { 0xFFFFFFFCu, 0x1090D200u, 0x42757474u, true },
    { 0xFFFFFFFCu, 0x1090D204u, 0x2020426Fu, true },
    { 0xFFFFFFFCu, 0x1090DF30u, 0x05414275u, true },
    { 0xFFFFFFFCu, 0x1090DF34u, 0x74742005u, true },
    { 0xFFFFFFFCu, 0x1090DF9Cu, 0x6E792062u, true },
    { 0xFFFFFFFCu, 0x1090DFA0u, 0x75747420u, true },
    { 0xFFFFFFFCu, 0x1090E25Cu, 0x20054142u, true },
    { 0xFFFFFFFCu, 0x1090E260u, 0x75747420u, true },
    { 0xFFFFFFFCu, 0x10910F58u, 0x08427574u, true },
    { 0xFFFFFFFCu, 0x10910F5Cu, 0x74202773u, true },
    { 0xFFFFFFFCu, 0x10910F8Cu, 0x08054142u, true },
    { 0xFFFFFFFCu, 0x10910F90u, 0x75747420u, true },
    { 0xFFFFFFFCu, 0x1091192Cu, 0x61742042u, true },
    { 0xFFFFFFFCu, 0x10911930u, 0x75747420u, true },
    { 0xFFFFFFFCu, 0x10911998u, 0x61742042u, true },
    { 0xFFFFFFFCu, 0x1091199Cu, 0x75747420u, true },
    { 0xFFFFFFFCu, 0x10911A04u, 0x61742042u, true },
    { 0xFFFFFFFCu, 0x10911A08u, 0x75747420u, true },
    { 0xFFFFFFFCu, 0x1091208Cu, 0x61742042u, true },
    { 0xFFFFFFFCu, 0x10912090u, 0x75747420u, true },
    { 0xFFFFFFFCu, 0x10913868u, 0x62757474u, true },
    { 0xFFFFFFFCu, 0x1091386Cu, 0x20010544u, true },
    { 0xFFFFFFFCu, 0x10918384u, 0x6F6E2D62u, true },
    { 0xFFFFFFFCu, 0x10918388u, 0x75747420u, true },
    { 0xFFFFFFFCu, 0x1091A7C8u, 0x20627574u, true },
    { 0xFFFFFFFCu, 0x1091A7CCu, 0x74202105u, true },
    { 0xFFFFFFFCu, 0x1091A848u, 0x62757474u, true },
    { 0xFFFFFFFCu, 0x1091A84Cu, 0x20212104u, true },
    { 0xFFFFFFFCu, 0x1091A85Cu, 0x62757474u, true },
    { 0xFFFFFFFCu, 0x1091A860u, 0x20206361u, true },
    { 0xFFFFFFFCu, 0x1091A954u, 0x05446275u, true },
    { 0xFFFFFFFCu, 0x1091A958u, 0x74742005u, true },
    { 0xFFFFFFFCu, 0x1091AEA4u, 0x05446275u, true },
    { 0xFFFFFFFCu, 0x1091AEA8u, 0x74742005u, true },
    { 0xFFFFFFFCu, 0x1091AED4u, 0x61206275u, true },
    { 0xFFFFFFFCu, 0x1091AED8u, 0x74742005u, true },
    { 0xFFFFFFFCu, 0x1091AF18u, 0x75722062u, true },
    { 0xFFFFFFFCu, 0x1091AF1Cu, 0x75747420u, true },
    { 0xFFFFFFFCu, 0x1091AF2Cu, 0x20612062u, true },
    { 0xFFFFFFFCu, 0x1091AF30u, 0x75747420u, true },
    { 0xFFFFFFFCu, 0x1091B044u, 0x44627574u, true },
    { 0xFFFFFFFCu, 0x1091B048u, 0x74202005u, true },
    { 0xFFFFFFFCu, 0x1091B4B4u, 0x62757474u, true },
    { 0xFFFFFFFCu, 0x1091B4B8u, 0x202E2E2Eu, true },
    { 0xFFFFFFFCu, 0x1091C04Cu, 0x20627574u, true },
    { 0xFFFFFFFCu, 0x1091C050u, 0x74202E2Eu, true },
    { 0xFFFFFFFCu, 0x1091C14Cu, 0x42757474u, true },
    { 0xFFFFFFFCu, 0x1091C150u, 0x20054021u, true },
    { 0xFFFFFFFCu, 0x1091C190u, 0x62757474u, true },
    { 0xFFFFFFFCu, 0x1091C194u, 0x202C2079u, true },
    { 0xFFFFFFFCu, 0x1091D030u, 0x68652062u, true },
    { 0xFFFFFFFCu, 0x1091D034u, 0x75747420u, true },
    { 0xFFFFFFFCu, 0x1091DA88u, 0x62757474u, true },
    { 0xFFFFFFFCu, 0x1091DA8Cu, 0x2020666Fu, true },
    { 0xFFFFFFFCu, 0x1091F278u, 0x62757474u, true },
    { 0xFFFFFFFCu, 0x1091F27Cu, 0x2005402Eu, true },
    { 0xFFFFFFFCu, 0x1091F45Cu, 0x62757474u, true },
    { 0xFFFFFFFCu, 0x1091F460u, 0x20200540u, true },
    { 0xFFFFFFFCu, 0x1091F8ACu, 0x62757474u, true },
    { 0xFFFFFFFCu, 0x1091F8B0u, 0x202E0E3Cu, true },
    { 0xFFFFFFFCu, 0x1091F8ECu, 0x61206275u, true },
    { 0xFFFFFFFCu, 0x1091F8F0u, 0x7474202Eu, true },
    { 0xFFFFFFFCu, 0x10920B70u, 0x20627574u, true },
    { 0xFFFFFFFCu, 0x10920B74u, 0x74203F21u, true },
    { 0xFFFFFFFCu, 0x10921330u, 0x62757474u, true },
    { 0xFFFFFFFCu, 0x10921334u, 0x2020626Fu, true },
    { 0xFFFFFFFCu, 0x10923830u, 0x20612062u, true },
    { 0xFFFFFFFCu, 0x10923834u, 0x75747420u, true },
    { 0xFFFFFFFCu, 0x109238ECu, 0x2C016275u, true },
    { 0xFFFFFFFCu, 0x109238F0u, 0x74742020u, true },
    { 0xFFFFFFFCu, 0x10923B6Cu, 0x65206275u, true },
    { 0xFFFFFFFCu, 0x10923B70u, 0x74742020u, true },
    { 0xFFFFFFFCu, 0x10923C48u, 0x2C206275u, true },
    { 0xFFFFFFFCu, 0x10923C4Cu, 0x74742020u, true },
    { 0xFFFFFFFCu, 0x10923CB4u, 0x752C2062u, true },
    { 0xFFFFFFFCu, 0x10923CB8u, 0x75747420u, true },
    { 0xFFFFFFFCu, 0x10923D30u, 0x20627574u, true },
    { 0xFFFFFFFCu, 0x10923D34u, 0x74202062u, true },
    { 0xFFFFFFFCu, 0x1092A350u, 0x42757474u, true },
    { 0xFFFFFFFCu, 0x1092A354u, 0x20054020u, true },
    { 0xFFFFFFFCu, 0x1092A474u, 0x74204275u, true },
    { 0xFFFFFFFCu, 0x1092A478u, 0x74742027u, true },
    { 0xFFFFFFFCu, 0x1092A584u, 0x62757474u, true },
    { 0xFFFFFFFCu, 0x1092A588u, 0x20010540u, true },
    { 0xFFFFFFFCu, 0x1092A5D8u, 0x05416275u, true },
    { 0xFFFFFFFCu, 0x1092A5DCu, 0x74742020u, true },
    { 0xFFFFFFFCu, 0x1092A764u, 0x74204275u, true },
    { 0xFFFFFFFCu, 0x1092A768u, 0x74742005u, true },
    { 0xFFFFFFFCu, 0x1093031Cu, 0x62757474u, true },
    { 0xFFFFFFFCu, 0x10930320u, 0x20206275u, true },
    { 0xFFFFFFFCu, 0x10940684u, 0x20054442u, true },
    { 0xFFFFFFFCu, 0x10940688u, 0x75747420u, true },
    { 0xFFFFFFFCu, 0x10940D20u, 0x20627574u, true },
    { 0xFFFFFFFCu, 0x10940D24u, 0x74200540u, true },
    { 0xFFFFFFFCu, 0x10940EECu, 0x20054462u, true },
    { 0xFFFFFFFCu, 0x10940EF0u, 0x75747420u, true },
    { 0xFFFFFFFCu, 0x10942C18u, 0x62757474u, true },
    { 0xFFFFFFFCu, 0x10942C1Cu, 0x2020626Fu, true },
#endif
};
static const int NUM_RULES = sizeof(rules)/sizeof(rules[0]);

static bool lookup_resp32(uint32_t addr_word, uint32_t* resp32_out) {
    for (int i = 0; i < NUM_RULES; ++i) {
        if (!rules[i].enable) continue;
        if ((addr_word & rules[i].mask) == (rules[i].match & rules[i].mask)) {
            *resp32_out = rules[i].resp32;
            return true;
        }
    }
    return false;
}

/* Token layout matches n64_respond_tokens.pio with shift_right OUT:
 *   bits [15: 0] = SKIP, bits [31:16] = DATA.
 */
static inline uint32_t make_token(uint16_t skip, uint16_t data) {
    return ((uint32_t)data << 16) | skip;
}

/* DEBUG: capture snooped halfwords for the burst currently in flight, until
 * a per-halfword timeout elapses or max_hw is reached. Does NOT bail out
 * just because the capture SM has already latched a new address — that can
 * happen from unrelated bus activity interleaved between this burst's own
 * pulses without the responder's current token schedule actually being
 * reset (the reset only happens once the main loop itself processes that
 * queued address, on a later iteration, not while we're still in here).
 * Bailing on it early was truncating captures well before the burst's own
 * real activity was done. */
static int snoop_capture_burst(PIO pio_snoop, uint sm_snoop, PIO pio_cap, uint sm_cap,
                                uint16_t* hw, int max_hw, uint32_t timeout_us_per_hw) {
    int got = 0;
    for (int i = 0; i < max_hw; ++i) {
        uint64_t deadline = time_us_64() + timeout_us_per_hw;
        for (;;) {
            if (!pio_sm_is_rx_fifo_empty(pio_snoop, sm_snoop)) break;
            if (time_us_64() > deadline) return got;
        }
        hw[i] = (uint16_t)pio_sm_get(pio_snoop, sm_snoop);
        got = i + 1;
    }
    return got;
}

/* Render halfwords as hex + a best-effort ASCII strip (big-endian bytes per
 * halfword, matching how text is laid out in the ROM). */
static void snoop_print_hw(const uint16_t* hw, int got) {
    for (int i = 0; i < got; ++i) printf(" %04X", hw[i]);
    printf("  |");
    for (int i = 0; i < got; ++i) {
        uint8_t hi = hw[i] >> 8, lo = hw[i] & 0xFF;
        putchar((hi >= 32 && hi < 127) ? (char)hi : '.');
        putchar((lo >= 32 && lo < 127) ? (char)lo : '.');
    }
    printf("|\n");
}

int main_dumb() {
    stdio_init_all();
    gpio_init(CART_EN_PIN);
    gpio_set_dir(CART_EN_PIN, true);
    gpio_put(CART_EN_PIN, 0);   // CBT closed, cart connected

    // Heartbeat so we know it's alive
    gpio_init(STATUS_LED_PIN);
    gpio_set_dir(STATUS_LED_PIN, true);
    static repeating_timer_t t;
    add_repeating_timer_ms(2000, led_heartbeat_cb, NULL, &t);

    for (;;) tight_loop_contents();
}
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

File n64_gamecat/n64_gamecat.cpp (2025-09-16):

/**
 * Copyright (c) 2020 Raspberry Pi (Trading) Ltd.
 *
 * SPDX-License-Identifier: BSD-3-Clause
 */
// IMPORTANT
// PICO_USE_GPIO_COPROCESSOR from gpio.h in the pico sdk should be set to 0
#include <stdio.h>

#define UART        0
#define PIN_UART_TX 44
#define PIN_UART_RX 45

#include "pico/stdlib.h"
#include "pico/multicore.h"
#include "hardware/pio.h"
#include "hardware/clocks.h"
#include "hardware/gpio.h"
#include "Wire.h"
#include "gpio_cfg.h"
#include <cinttypes>
#include <hardware/dma.h>
#include <string>
#include "state.h"

#include "console.pio.h"
#include "cartridge.pio.h"
#include "control.pio.h"

#pragma clang diagnostic push
#pragma ide diagnostic ignored "EndlessLoop"

//#define SIO_BASE            0xD0000000
#define GPIO_IN_OFFSET      0x04
#define GPIO_OUT_OFFSET     0x10
#define GPIO_OE_OFFSET      0x30

#define GPIO_IN             (*(volatile uint32_t *)(SIO_BASE + GPIO_IN_OFFSET))
#define GPIO_OUT            (*(volatile uint32_t *)(SIO_BASE + GPIO_OUT_OFFSET))
#define GPIO_OE             (*(volatile uint32_t *)(SIO_BASE + GPIO_OE_OFFSET))

#define GPIO_OE_BANK0   (*(volatile uint32_t *)(SIO_BASE + GPIO_OE_OFFSET))
#define GPIO_OE_BANK1   (*(volatile uint32_t *)(SIO_BASE + GPIO_OE_OFFSET + 0x04))

#define GPIO_IN_BANK0   (*(volatile uint32_t *)(SIO_BASE + GPIO_IN_OFFSET))
#define GPIO_IN_BANK1   (*(volatile uint32_t *)(SIO_BASE + GPIO_IN_OFFSET + 0x04)) // Adjust the offset as per the datasheet

#define GPIO_OUT_BANK0   (*(volatile uint32_t *)(SIO_BASE + GPIO_OUT_OFFSET))
#define GPIO_OUT_BANK1   (*(volatile uint32_t *)(SIO_BASE + GPIO_OUT_OFFSET + 0x04)) // Adjust the offset as per the datasheet

#define NUM_SAMPLES 5000


typedef struct {
    uint16_t val_h;
    uint16_t val_l;
} val_parts_t;

typedef union {
    val_parts_t valParts;
    uint32_t val;

} val_t;

static uint64_t console_mask = 0;
static uint64_t cartridge_mask = 0;
static uint64_t control_mask = 0;
static uint64_t full_mask_co = 0;
static uint64_t full_mask_ca = 0;
static uint64_t flag_mask = 0;

static State state = State::IDLE;
static val_t addr = {0};
static val_t data = {0};
static uint32_t regs_low = 0;
static uint32_t regs_high = 0;

volatile uint64_t curr_val = 0;

volatile uint32_t con_data = 0;
volatile uint32_t car_data = 0;
volatile uint32_t sig_data = 69; // widened to 32-bit for DMA transfers (burst-only)
// Buffer for control PIO samples (DMA writes 8-bit FIFO bytes here)
static volatile uint8_t control_samples[256];
static const size_t CONTROL_SAMPLE_COUNT = 256; // number of bytes to capture per burst

static bool console_talking = true;

// console "talking"
__attribute__((always_inline))
inline void set_console() {
    gpio_set_dir_in_masked64(console_mask);
    gpio_set_dir_out_masked64(cartridge_mask);
    console_talking = true;
}

// cartridge "talking"
__attribute__((always_inline))
inline void set_cartridge() {
    gpio_set_dir_out_masked64(console_mask);
    gpio_set_dir_in_masked64(cartridge_mask);
    console_talking = false;
}

__attribute__((always_inline))
inline void dump_to_console(uint64_t val) {
    gpio_put_masked64(console_mask, (val & cartridge_mask) << 16);
    gpio_put_masked64(flag_mask, (val & control_mask) << 6);
}

__attribute__((always_inline))
inline void dump_to_cartridge(uint64_t val) {
    gpio_put_masked64(flag_mask, (val & control_mask) << 6);

}

void init_gpio() {
    //configure_gpio_pins();
    for (uint i = 0; i < 16; ++i) {
        console_mask |= (uint64_t) 1 << (uint64_t) console_pins[i];
        cartridge_mask |= (uint64_t) 1 << (uint64_t) cartridge_pins[i];

        gpio_init(console_pins[i]);
        gpio_init(cartridge_pins[i]);

        gpio_set_pulls(console_pins[i], true, false);
        gpio_set_pulls(cartridge_pins[i], true, false);
    }

    control_mask |= (uint64_t) 1 << ALE_H;
    control_mask |= (uint64_t) 1 << ALE_L;
    control_mask |= (uint64_t) 1 << READ;
    control_mask |= (uint64_t) 1 << WRITE;

    flag_mask |= (uint64_t) 1 << FLAG_ALE_H;
    flag_mask |= (uint64_t) 1 << FLAG_ALE_L;
    flag_mask |= (uint64_t) 1 << FLAG_READ;
    flag_mask |= (uint64_t) 1 << FLAG_WRITE;

    gpio_init(ALE_H);
    gpio_init(ALE_L);
    gpio_init(READ);
    gpio_init(WRITE);

    gpio_init(FLAG_ALE_H);
    gpio_init(FLAG_ALE_L);
    gpio_init(FLAG_WRITE);
    gpio_init(FLAG_READ);

    printf("Console   mask: 0x%" PRIx64 "\n", console_mask);
    printf("Cartridge mask: 0x%" PRIx64 "\n", cartridge_mask);
    printf("Control   mask: 0x%" PRIx64 "\n", control_mask);

    printf("uint size: %d\n", sizeof(uint));

    gpio_set_dir_in_masked64(control_mask);

    //full_mask_co = cartridge_mask | control_mask;
    //full_mask_ca = console_mask   | control_mask;

    //full_mask_co |= ((uint64_t)1 << GPIO_FLAG);
    //full_mask_ca |= ((uint64_t)1 << GPIO_FLAG);

    printf("Full CO   mask: 0x%" PRIx64 "\n", full_mask_co);
    printf("Full CA   mask: 0x%" PRIx64 "\n", full_mask_ca);

    gpio_set_pulls(ALE_H, true, false);
    gpio_set_pulls(ALE_L, true, false);
    gpio_set_pulls(READ, true, false);
    gpio_set_pulls(WRITE, true, false);

    gpio_set_pulls(FLAG_ALE_H, true, false);
    gpio_set_pulls(FLAG_ALE_L, true, false);
    gpio_set_pulls(FLAG_WRITE, true, false);
    gpio_set_pulls(FLAG_READ, true, false);

    gpio_set_dir(FLAG_ALE_H, true);
    gpio_set_dir(FLAG_ALE_L, true);
    gpio_set_dir(FLAG_WRITE, true);
    gpio_set_dir(FLAG_READ, true);

    // NEW
    gpio_set_dir(ALE_H, false);
    gpio_set_dir(ALE_L, false);
    gpio_set_dir(WRITE, false);
    gpio_set_dir(READ, false);

    //gpio_set_mask64(console_mask);
}

void core1_loop() {
    printf("CORE1\n");
    while (true) {
        //if (console_talking) {
        dump_to_cartridge(curr_val);
        //} else {
        //dump_to_console(curr_val);
        //}
    }
}
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

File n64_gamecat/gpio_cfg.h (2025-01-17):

#ifndef N64_GAMECAT_GPIO_CFG_H
#define N64_GAMECAT_GPIO_CFG_H

#define PIN_MIN  2
#define PIN_MAX  39

#define CA_AD0  2
#define CA_AD1  3
#define CA_AD2  4
#define CA_AD3  5
#define CA_AD4  6
#define CA_AD5  7
#define CA_AD6  8
#define CA_AD7  9
#define CA_AD8  10
#define CA_AD9  11
#define CA_AD10 12
#define CA_AD11 13
#define CA_AD12 14
#define CA_AD13 15
#define CA_AD14 16
#define CA_AD15 17

#define CO_AD0  18
#define CO_AD1  19
#define CO_AD2  20
#define CO_AD3  21
#define CO_AD4  22
#define CO_AD5  23
#define CO_AD6  24
#define CO_AD7  25
#define CO_AD8  26
#define CO_AD9  27
#define CO_AD10 28
#define CO_AD11 29
#define CO_AD12 30
#define CO_AD13 31
#define CO_AD14 32
#define CO_AD15 33

uint console_pins[] = {

        CO_AD0,
        CO_AD1,
        CO_AD2,
        CO_AD3,
        CO_AD4,
        CO_AD5,
        CO_AD6,
        CO_AD7,
        CO_AD8,
        CO_AD9,
        CO_AD10,
        CO_AD11,
        CO_AD12,
        CO_AD13,
        CO_AD14,
        CO_AD15,
};
uint cartridge_pins[] = {
        CA_AD0,
        CA_AD1,
        CA_AD2,
        CA_AD3,
        CA_AD4,
        CA_AD5,
        CA_AD6,
        CA_AD7,
        CA_AD8,
        CA_AD9,
        CA_AD10,
        CA_AD11,
        CA_AD12,
        CA_AD13,
        CA_AD14,
        CA_AD15,
};

#define ALE_H 34
#define ALE_L 35
#define WRITE 36
#define READ  37

#define FLAG_ALE_H 40
#define FLAG_ALE_L 41
#define FLAG_WRITE 42
#define FLAG_READ 43

#endif //N64_GAMECAT_GPIO_CFG_H

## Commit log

2020-08-29 Add PCB files
    [test_pcb-B_Cu.gbr, test_pcb-B_Mask.gbr, test_pcb-B_Paste.gbr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]
2020-09-03 Use pins other than 31-35, since they can't be used as GPIOHS
    [n64_gamecat-B_Cu.gbr, n64_gamecat-B_Mask.gbr, n64_gamecat-B_Paste.gbr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]
2020-09-03 Generate version 0.2 PCB Gerber files
    [n64_gamecat-B_Cu.gbr, n64_gamecat-B_Mask.gbr, n64_gamecat-B_Paste.gbr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]
2021-02-19 Add rev 3 PCB
    [n64_gamecat-B_Cu.gbr, n64_gamecat-B_Mask.gbr, n64_gamecat-B_Paste.gbr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]
2024-10-18 2024 rewrite
    [n64_gamecat-B_Cu.gbr, n64_gamecat-B_Mask.gbr, n64_gamecat-B_Paste.gbr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]
2024-10-29 V0.6 PCB
    [n64_gamecat_rp2350b-B_Cu.gbr, n64_gamecat_rp2350b-B_Mask.gbr, n64_gamecat_rp2350b-B_Paste.gbr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]
2024-11-01 v0.7 PCB; prep for 2350
    [n64_gamecat_rp2350b-B_Cu.gbr, n64_gamecat_rp2350b-B_Mask.gbr, n64_gamecat_rp2350b-B_Paste.gbr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]
2024-11-02 Add v0.8 PCB
    [n64_gamecat_rp2350b.dsn, n64_gamecat_rp2350b.kicad_pcb, n64_gamecat_rp2350b.kicad_sch]
2024-12-27 Start adding software; add data plotter; add real .8 gerber
    [n64_gamecat_rp2350b-B_Cu.gbr, n64_gamecat_rp2350b-B_Mask.gbr, n64_gamecat_rp2350b-B_Paste.gbr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]
2024-12-27 Improve sample rate
    [n64_gamecat_rp2350b-B_Cu.gbr, n64_gamecat_rp2350b-B_Mask.gbr, n64_gamecat_rp2350b-B_Paste.gbr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]
2024-12-27 Add reminder for switching to SIO instead of GPIO coprocessor
2025-01-17 Add v0.9 PCB
    [RP2350A-QFN60.step, RP2350B-QFN80.step, bom.csv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]
2025-01-17 Initial PIO <-> DMA implementation
2025-09-15 Updates to improve DMA
    [n64_gamecat_rp2350b-B_Cu.gbr, n64_gamecat_rp2350b-B_Mask.gbr, n64_gamecat_rp2350b-B_Paste.gbr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]
2025-09-16 Yet another rewrite and redesign
    [switched.dsn]
2026-04-17 Finish switched implementation
2026-04-25 Misc changes; add OoT decomp
    [BOM-n64_gamecat_rp2350b.csv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]
2026-08-07 Somewhat working with debug logging
    [BOM-n64_gamecat_rp2350b.csv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]
